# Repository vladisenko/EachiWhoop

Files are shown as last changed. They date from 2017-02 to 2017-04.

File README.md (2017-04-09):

# EachiWhoop v2

Changes compared to the v1:
- Upgrade CPU to STM32F303CCT6
- Add support AFHDS A2 protocol with telemetry (tested with FlySky FS-i6 transmitter)
- Add pads for the UART
- Board can operate with 2S battery (not tested yet)

# EachiWhoop

Micro size flight controller board for Eachine E010 frame.

Specifications:
- Processor: STM32F103CB
- Gyro: MPU6500
- Receiver: Flysky AFHDS
- Weight: 1.44 grams
- Voltage: 1S Lipo battery input
- Firmware: patched Betaflight

PCB with "2oz 0.8mm" option from [OSH Park](https://oshpark.com/shared_projects/v77xm6IP).

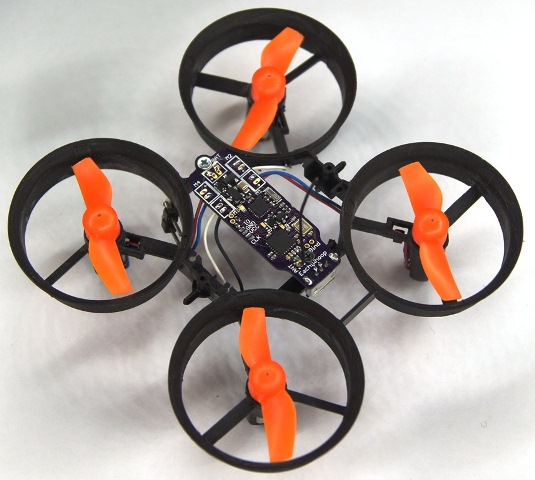
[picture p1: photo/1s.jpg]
pcb on E010 frame


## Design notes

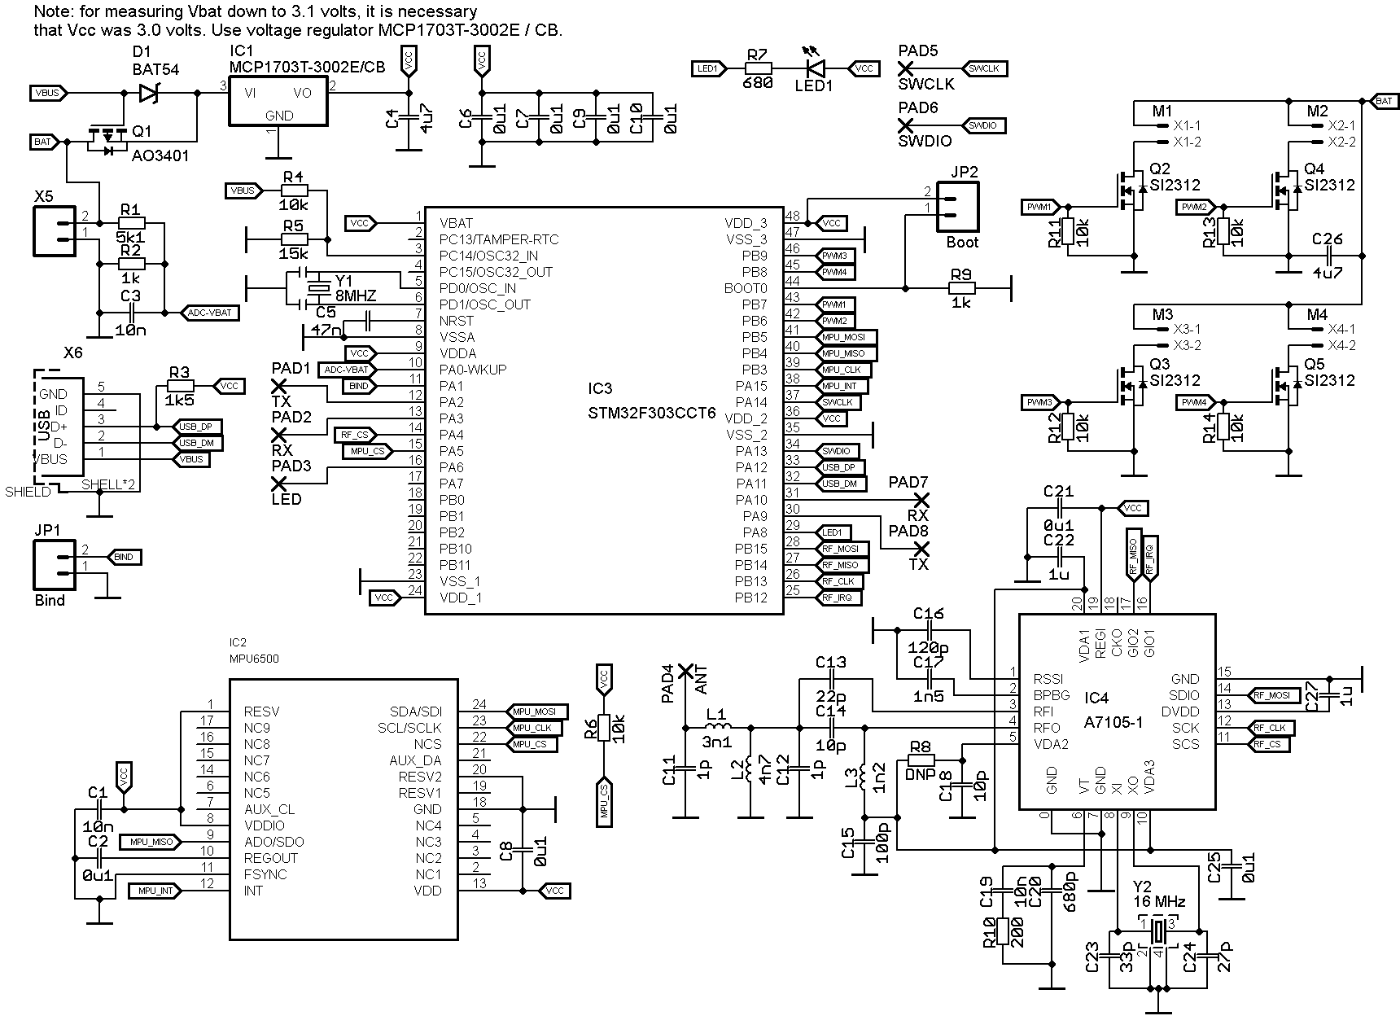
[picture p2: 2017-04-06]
hw/v.2/eachi-v2-schematic.png

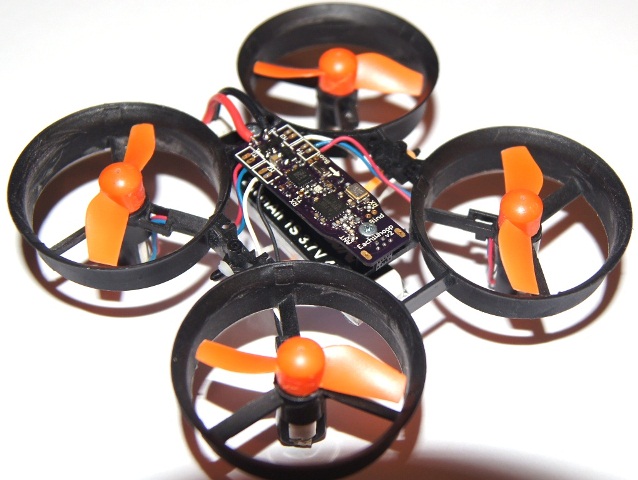
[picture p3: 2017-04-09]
photo/4s.JPG

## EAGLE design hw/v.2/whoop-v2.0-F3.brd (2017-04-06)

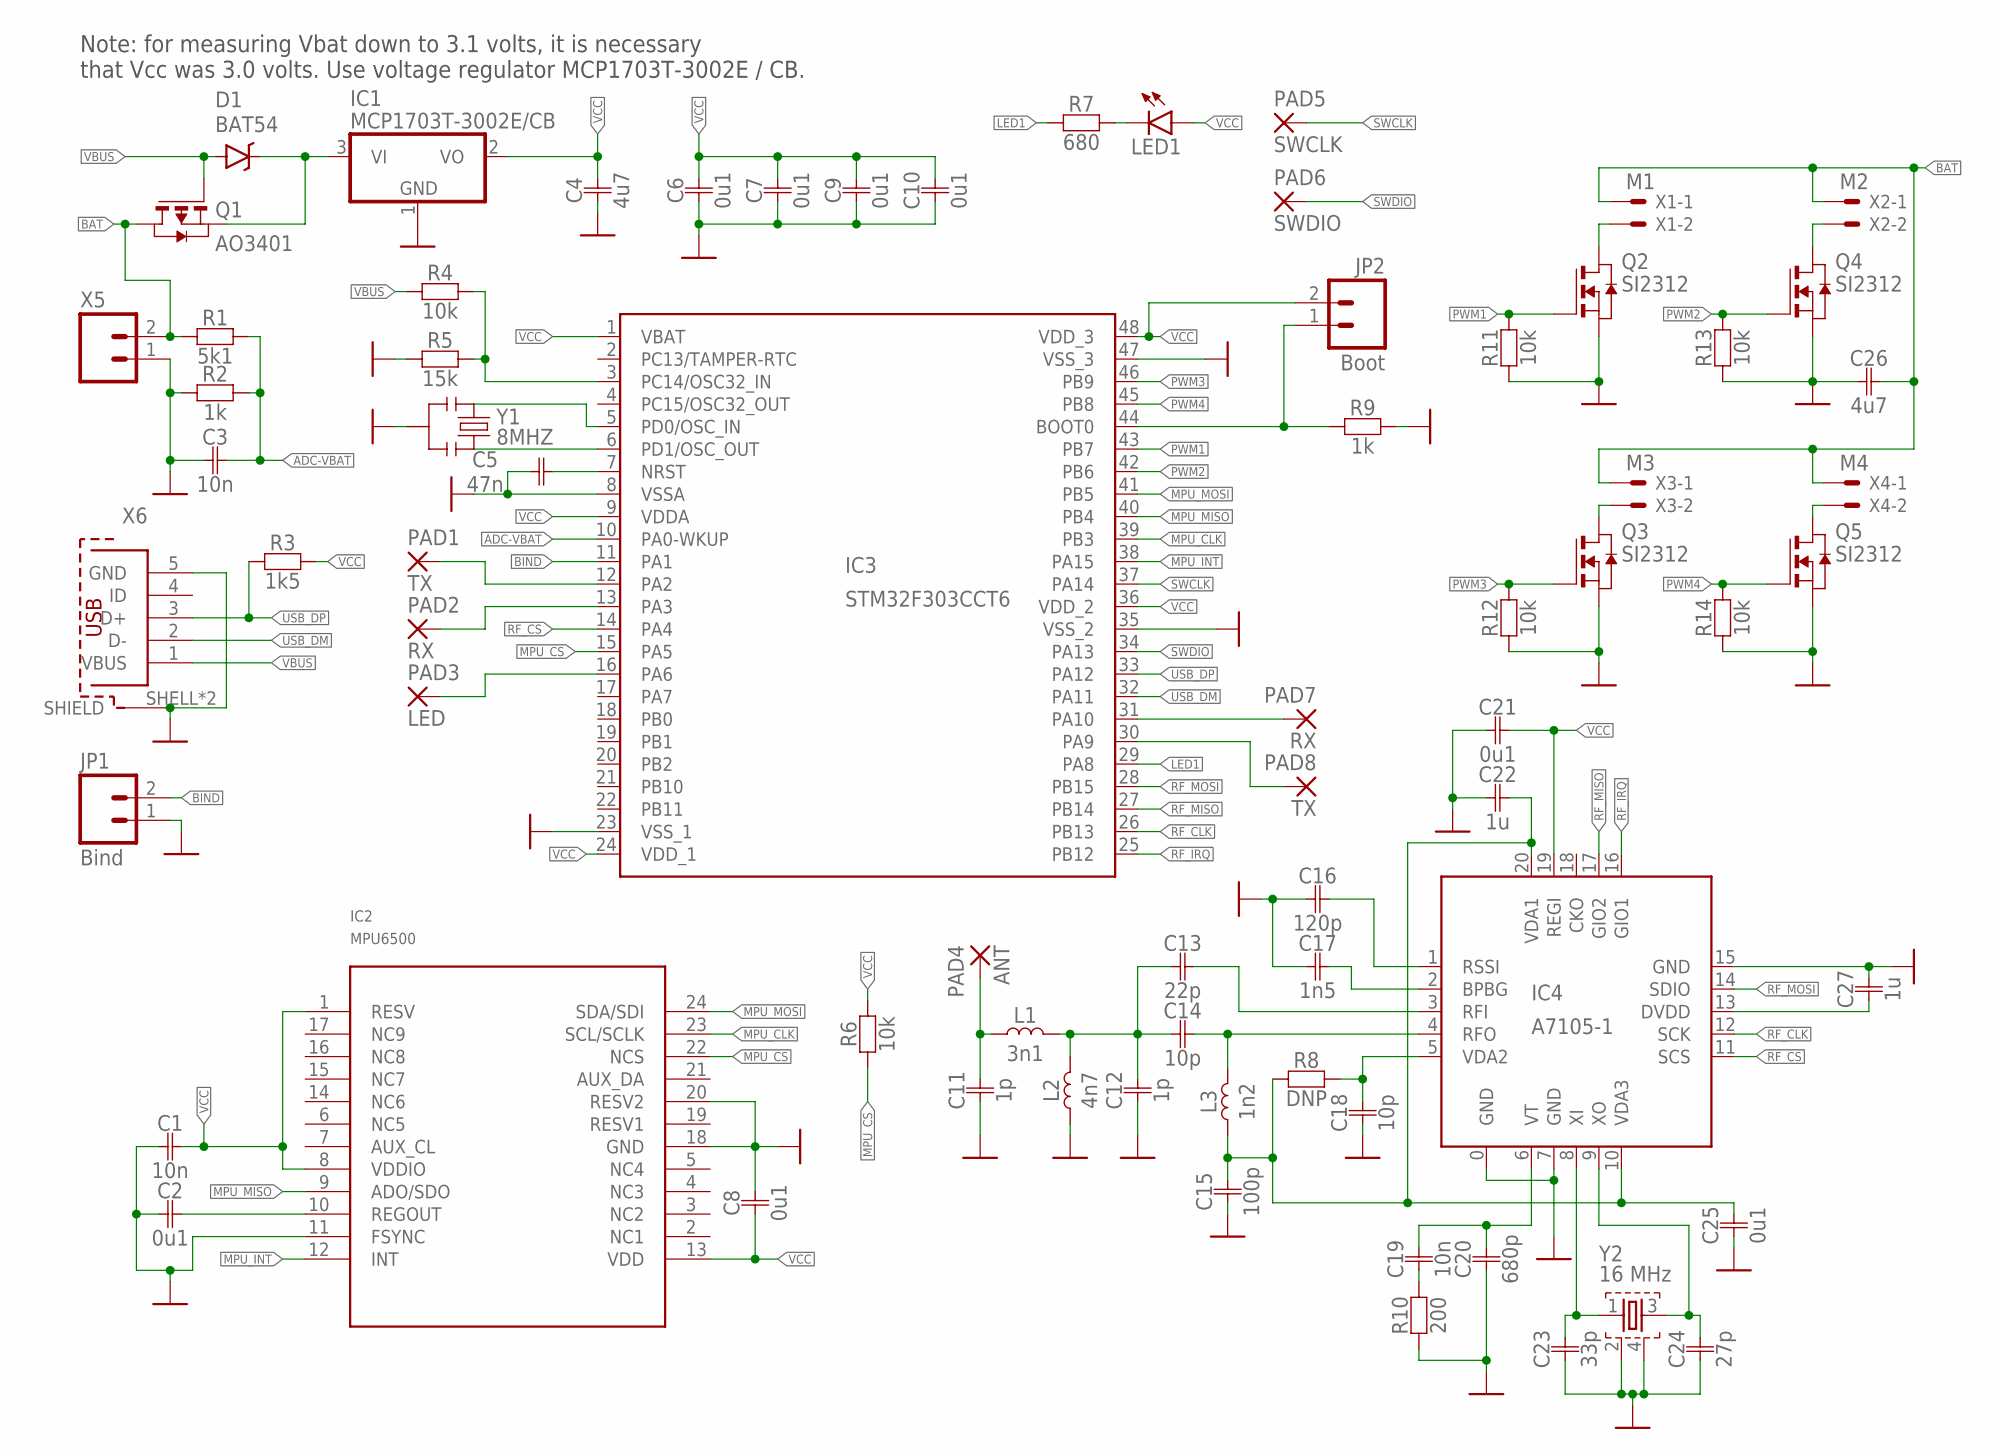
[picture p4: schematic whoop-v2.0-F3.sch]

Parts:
C1, C3, C19: 10n; 0402
C2, C6, C7, C8, C9, C10, C21, C25: 0u1; 0402
C4, C26: 4u7; 0805
C5: 47n; 0402
C11, C12: 1p; 0402
C13: 22p; 0402
C14, C18: 10p; 0402
C15: 100p; 0402
C16: 120p; 0402
C17: 1n5; 0402
C20: 680p; 0402
C22, C27: 1u; 0402
C23: 33p; 0402
C24: 27p; 0402
D1: BAT54; SOD-323
IC1: MCP1703T-3002E/CB; SOT23
IC2: MPU6500; LEAD-QFN24
IC3: STM32F303CCT6; LQFP48
IC4: A7105-1; QFN20-1
JP1: Bind; 1X02_1.27MM
JP2: Boot; 1X02_1.27MM
L1: 3n1; 0402
L2: 4n7; 0402
L3: 1n2; 0402
LED1: LED-RED0603; LED-0603
PAD1: TX; SMD_R0,635
PAD2, PAD7: RX; 1/0,6
PAD3: LED; 1/0,6
PAD4: ANT; 1/0,6
PAD5: SWCLK; SMD_R0,635
PAD6: SWDIO; SMD_R0,635
PAD8: TX; 1/0,6
Q1: AO3401; SOT-23
Q2, Q3, Q4, Q5: SI2312; SOT-23
R1: 5k1; 0402
R2, R9: 1k; 0402
R3: 1k5; 0402
R4, R6, R11, R12, R13, R14: 10k; 0402
R5: 15k; 0402
R7: 680; 0402
R8: DNP; 0402
R10: 200; 0402
X1: M1; 53047-02
X2: M2; 53047-02
X3: M3; 53047-02
X4: M4; 53047-02
X5: M022MM; 1X02_2MM
X6: 614105150721
Y1: 8MHZ; RESONATOR-SMD
Y2: 16 MHz; FA-20H

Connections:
ADC-VBAT: C3.P$2, IC3.10 (PA0-WKUP), R1.P$1, R2.P$1
BAT: C26.P$2, Q1.1 (D), R1.P$2, X1.1, X2.1, X3.1, X4.1, X5.2
BIND: IC3.11 (PA1), JP1.2
GND: C1.P$1, C2.P$1, C3.P$1, C4.P$1, C5.P$1, C6.P$1, C7.P$1, C8.P$2, C9.P$1, C10.P$1, C11.P$1, C12.P$1, C15.P$1, C16.P$1, C17.P$1, C18.P$1, C20.P$1, C21.P$1, C22.P$1, C23.P$1, C24.P$1, C25.P$1, C26.P$1, C27.P$2, IC1.1 (GND), IC2.11 (FSYNC), IC2.18 (GND), IC2.20 (RESV2), IC3.8 (VSSA), IC3.23 (VSS_1), IC3.35 (VSS_2), IC3.47 (VSS_3), IC4.0 (GND), IC4.7 (GND), IC4.15 (GND), JP1.1, L2.P$1, Q2.2 (S), Q3.2 (S), Q4.2 (S), Q5.2 (S), R2.P$2, R5.P$2, R9.P$2, R10.P$1, R11.P$1, R12.P$1, R13.P$1, R14.P$1, X5.1, X6.5 (GND), X6.SHELL (SHIELD), X6.SHELL1 (SHIELD), Y1.2, Y2.2, Y2.4
LED1: IC3.29 (PA8), R7.P$1
M1+: Q2.1 (D), X1.2
M2+: Q4.1 (D), X2.2
M3+: Q3.1 (D), X3.2
M4+: Q5.1 (D), X4.2
MPU_CLK: IC2.23 (SCL/SCLK), IC3.39 (PB3)
MPU_CS: IC2.22 (NCS), IC3.15 (PA5), R6.P$1
MPU_INT: IC2.12 (INT), IC3.38 (PA15)
MPU_MISO: IC2.9 (ADO/SDO), IC3.40 (PB4)
MPU_MOSI: IC2.24 (SDA/SDI), IC3.41 (PB5)
unnamed: C13.P$2, IC4.3 (RFI)
unnamed: C12.P$2, C13.P$1, C14.P$1, L1.P$2, L2.P$2
unnamed: C2.P$2, IC2.10 (REGOUT)
unnamed: C14.P$2, IC4.4 (RFO), L3.P$1
unnamed: C23.P$2, IC4.8 (XI), Y2.1
unnamed: C24.P$2, IC4.9 (XO), Y2.3
unnamed: C17.P$2, IC4.2 (BPBG)
unnamed: C16.P$2, IC4.1 (RSSI)
unnamed: C19.P$2, C20.P$2, IC4.6 (VT)
unnamed: C27.P$1, IC4.13 (DVDD)
unnamed: C19.P$1, R10.P$2
unnamed: C15.P$2, C22.P$2, C25.P$2, IC4.10 (VDA3), IC4.20 (VDA1), L3.P$2, R8.P$1
unnamed: IC3.6 (PD1/OSC_OUT), Y1.3
unnamed: C18.P$2, IC4.5 (VDA2), R8.P$2
unnamed: LED1.C, R7.P$2
unnamed: IC3.12 (PA2), PAD1.1
unnamed: IC3.3 (PC14/OSC32_IN), R4.P$2, R5.P$1
unnamed: IC3.13 (PA3), PAD2.1
unnamed: IC3.44 (BOOT0), JP2.1, R9.P$1
unnamed: C11.P$2, L1.P$1, PAD4.1
unnamed: IC3.31 (PA10), PAD7.1
unnamed: IC3.16 (PA6), PAD3.1
unnamed: IC3.30 (PA9), PAD8.1
unnamed: IC3.5 (PD0/OSC_IN), Y1.1
unnamed: D1.C, IC1.3 (VI), Q1.2 (S)
unnamed: C5.P$2, IC3.7 (NRST)
PWM1: IC3.43 (PB7), Q2.3 (G), R11.P$2
PWM2: IC3.42 (PB6), Q4.3 (G), R13.P$2
PWM3: IC3.46 (PB9), Q3.3 (G), R12.P$2
PWM4: IC3.45 (PB8), Q5.3 (G), R14.P$2
RF_CLK: IC3.26 (PB13), IC4.12 (SCK)
RF_CS: IC3.14 (PA4), IC4.11 (SCS)
RF_IRQ: IC3.25 (PB12), IC4.16 (GIO1)
RF_MISO: IC3.27 (PB14), IC4.17 (GIO2)
RF_MOSI: IC3.28 (PB15), IC4.14 (SDIO)
SWCLK: IC3.37 (PA14), PAD5.1
SWDIO: IC3.34 (PA13), PAD6.1
USB_DM: IC3.32 (PA11), X6.2 (D-)
USB_DP: IC3.33 (PA12), R3.P$2, X6.3 (D+)
VBUS: D1.A, Q1.3 (G), R4.P$1, X6.1 (VBUS)
VCC: C1.P$2, C4.P$2, C6.P$2, C7.P$2, C8.P$1, C9.P$2, C10.P$2, C21.P$2, IC1.2 (VO), IC2.1 (RESV), IC2.8 (VDDIO), IC2.13 (VDD), IC3.1 (VBAT), IC3.9 (VDDA), IC3.24 (VDD_1), IC3.36 (VDD_2), IC3.48 (VDD_3), IC4.19 (REGI), JP2.2, LED1.A, R3.P$1, R6.P$2

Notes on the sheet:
Note: for measuring Vbat down to 3.1 volts, it is necessary that Vcc was 3.0 volts. Use voltage regulator MCP1703T-3002E / CB.

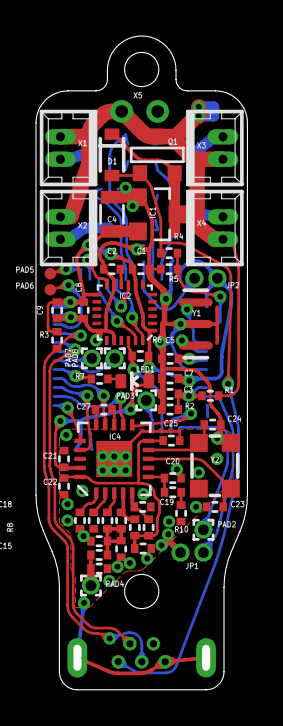
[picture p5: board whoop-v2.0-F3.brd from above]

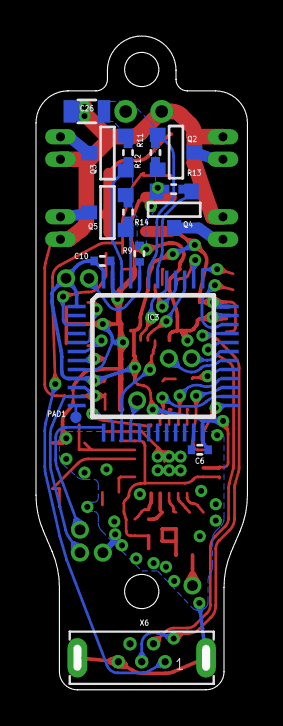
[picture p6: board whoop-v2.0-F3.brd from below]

Board: 2 copper layers, 11.7 x 36.3 mm, 73 parts (15 on the bottom side), 55 nets.

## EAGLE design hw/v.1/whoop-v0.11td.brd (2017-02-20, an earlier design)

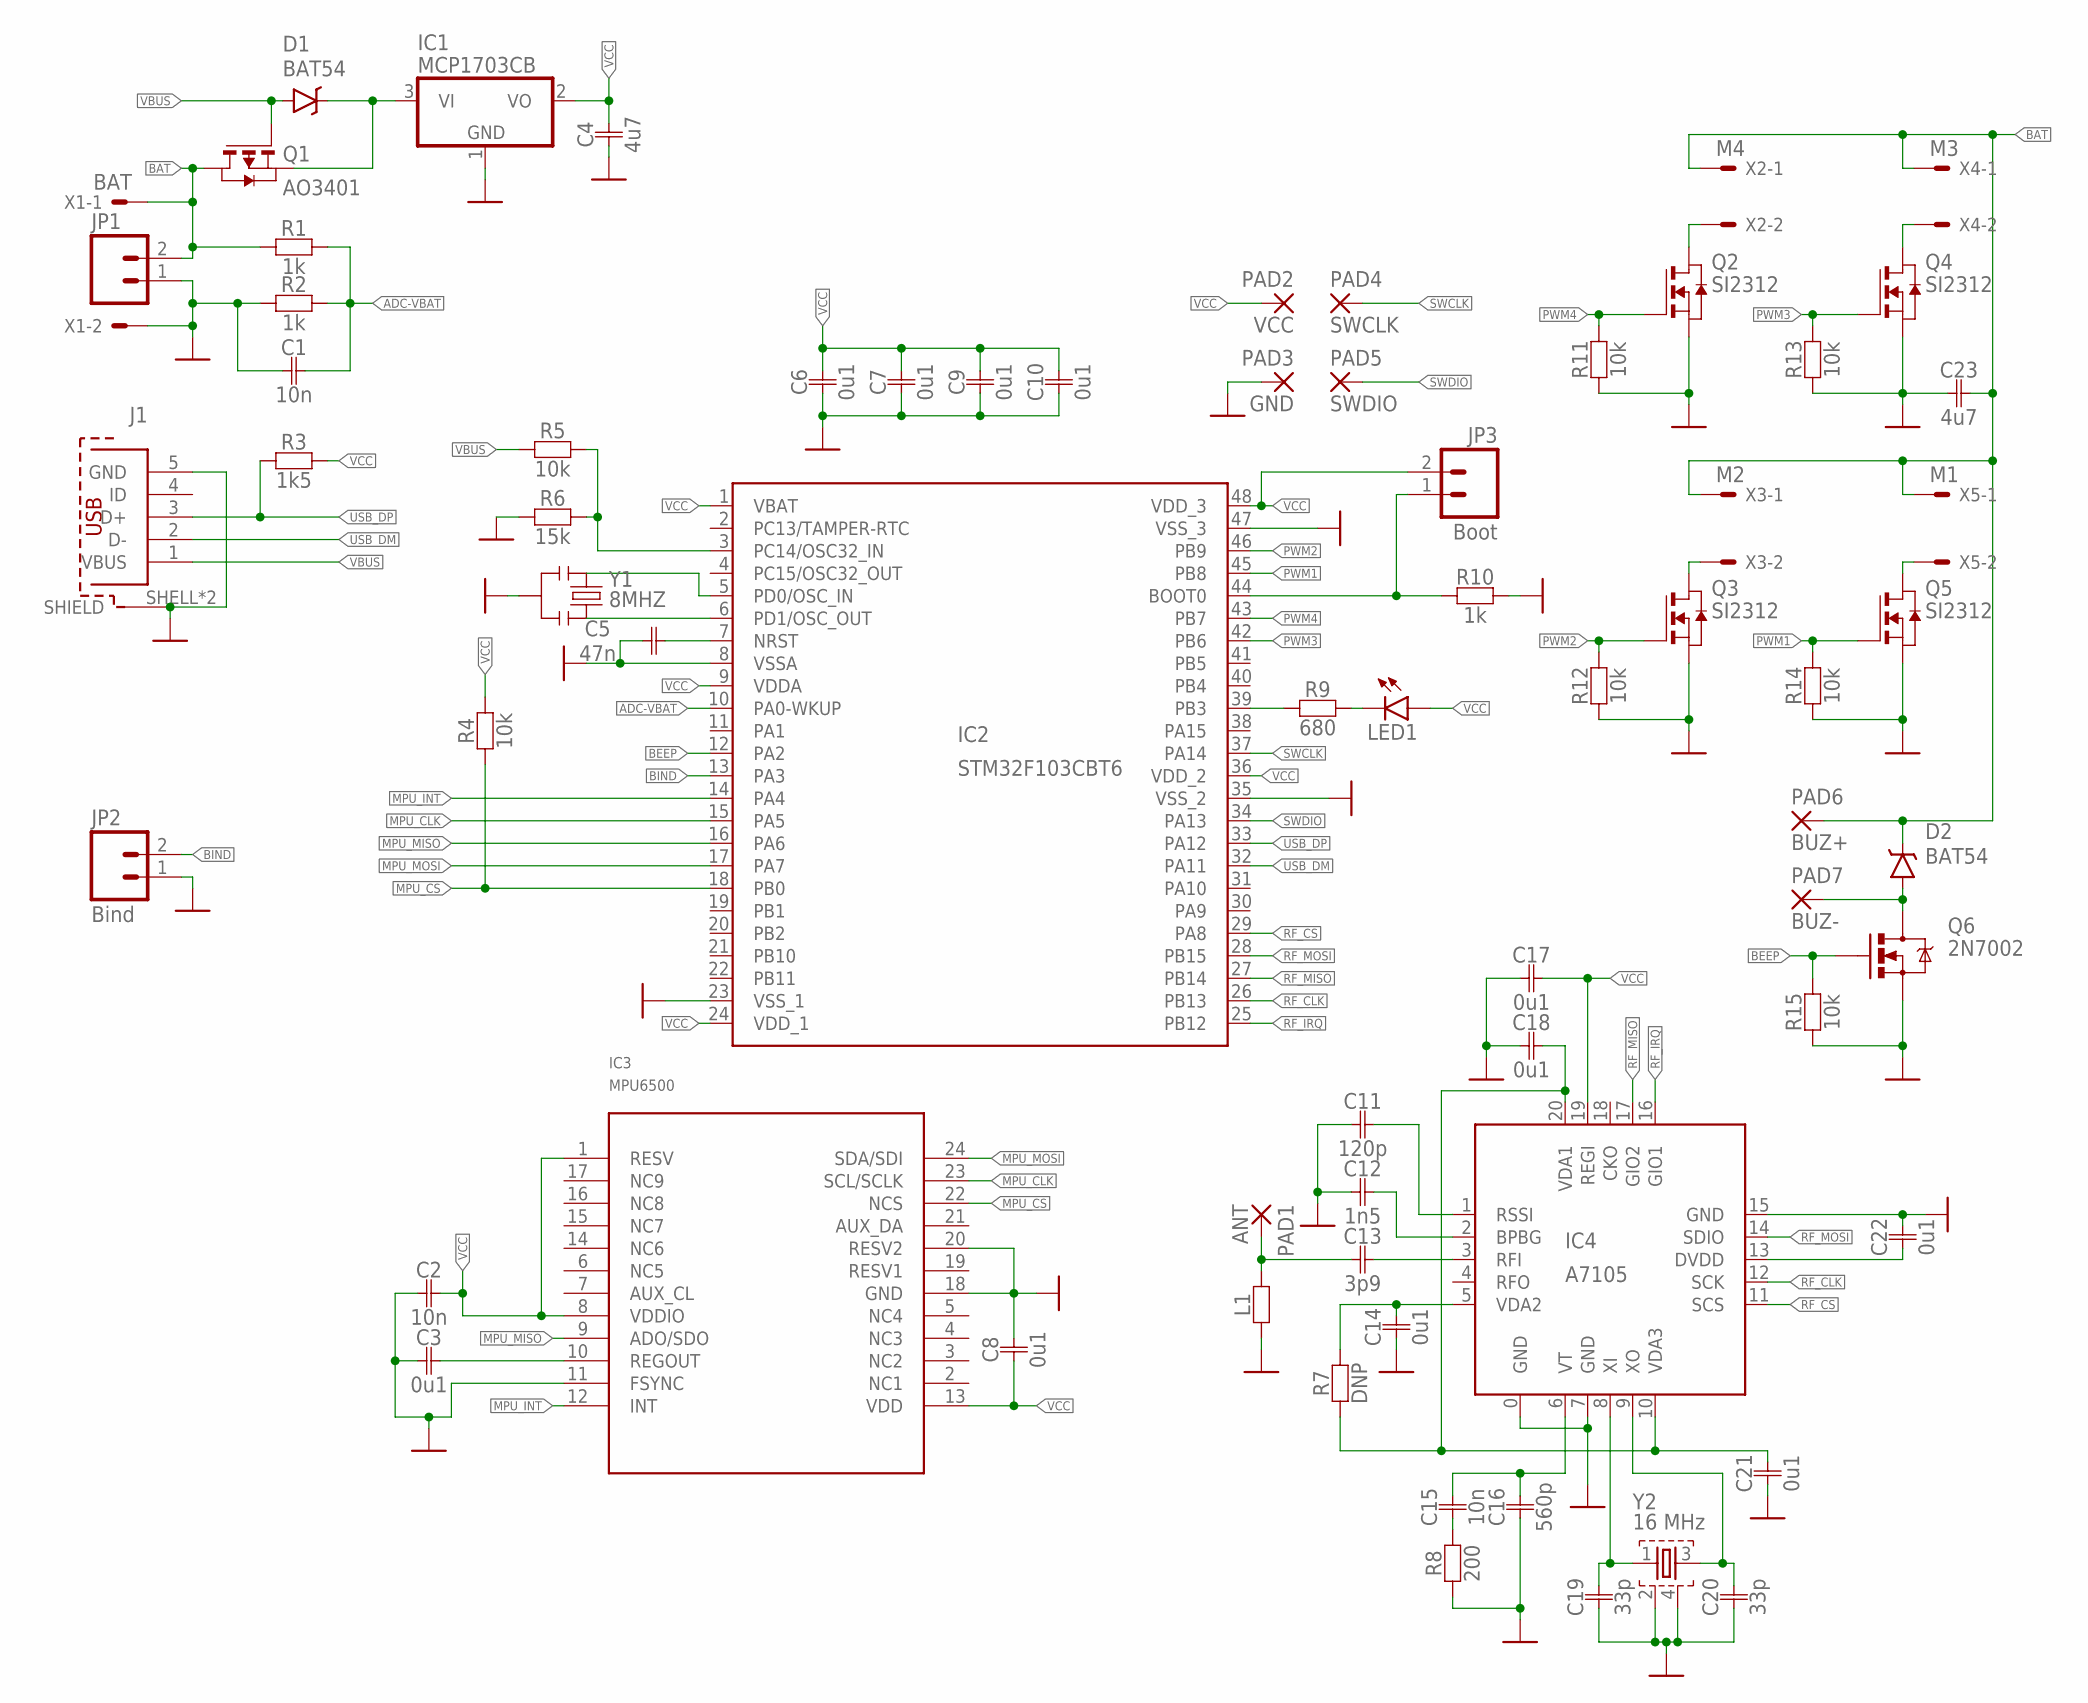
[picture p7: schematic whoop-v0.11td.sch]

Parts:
C1, C2, C15: 10n; 0402
C3, C6, C7, C8, C9, C10, C14, C17, C18, C21, C22: 0u1; 0402
C4, C23: 4u7; 0805
C5: 47n; 0402
C11: 120p; 0402
C12: 1n5; 0402
C13: 3p9; 0402
C16: 560p; 0402
C19, C20: 33p; 0402
D1, D2: BAT54; SOD-323
IC1: MCP1703CB; SOT23
IC2: STM32F103CBT6; LQFP48
IC3: MPU6500; LEAD-QFN24
IC4: A7105; QFN20
J1: 614105150721
JP1: M022MM; 1X02_2MM
JP2: Bind; 1X02_1.27MM
JP3: Boot; 1X02_1.27MM
L1: R0402; 0402
LED1: LED-RED0603; LED-0603
PAD1: ANT; 1,6/0,8
PAD2: VCC; SMD1,27-2,54
PAD3: GND; SMD1,27-2,54
PAD4: SWCLK; SMD1,27-2,54
PAD5: SWDIO; SMD1,27-2,54
PAD6: BUZ+; SMD1,27-2,54
PAD7: BUZ-; SMD1,27-2,54
Q1: AO3401; SOT-23
Q2, Q3, Q4, Q5: SI2312; SOT-23
Q6: 2N7002; SOT323
R1, R2, R10: 1k; 0402
R3: 1k5; 0402
R4, R5, R11, R12, R13, R14, R15: 10k; 0402
R6: 15k; 0402
R7: DNP; 0402
R8: 200; 0402
R9: 680; 0402
X1: BAT; 53047-02
X2: M4; 53047-02
X3: M2; 53047-02
X4: M3; 53047-02
X5: M1; 53047-02
Y1: 8MHZ; RESONATOR-SMD
Y2: 16 MHz; FA-20H

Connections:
ADC-VBAT: C1.P$2, IC2.10 (PA0-WKUP), R1.P$1, R2.P$1
BAT: C23.P$2, D2.C, JP1.2, PAD6.1, Q1.1 (D), R1.P$2, X1.1, X2.1, X3.1, X4.1, X5.1
BEEP: IC2.12 (PA2), Q6.1 (G), R15.P$2
BIND: IC2.13 (PA3), JP2.2
GND: C1.P$1, C2.P$1, C3.P$1, C4.P$1, C5.P$1, C6.P$1, C7.P$1, C8.P$2, C9.P$1, C10.P$1, C11.P$1, C12.P$1, C14.P$1, C16.P$1, C17.P$1, C18.P$1, C19.P$1, C20.P$1, C21.P$1, C22.P$2, C23.P$1, IC1.1 (GND), IC2.8 (VSSA), IC2.23 (VSS_1), IC2.35 (VSS_2), IC2.47 (VSS_3), IC3.11 (FSYNC), IC3.18 (GND), IC3.20 (RESV2), IC4.0 (GND), IC4.7 (GND), IC4.15 (GND), J1.5 (GND), J1.SHELL (SHIELD), J1.SHELL1 (SHIELD), JP1.1, JP2.1, L1.P$1, PAD3.1, Q2.2 (S), Q3.2 (S), Q4.2 (S), Q5.2 (S), Q6.2 (S), R2.P$2, R6.P$2, R8.P$1, R10.P$2, R11.P$1, R12.P$1, R13.P$1, R14.P$1, R15.P$1, X1.2, Y1.2, Y2.2, Y2.4
M1+: Q2.1 (D), X2.2
M2+: Q4.1 (D), X4.2
M3+: Q3.1 (D), X3.2
M4+: Q5.1 (D), X5.2
MPU_CLK: IC2.15 (PA5), IC3.23 (SCL/SCLK)
MPU_CS: IC2.18 (PB0), IC3.22 (NCS), R4.P$1
MPU_INT: IC2.14 (PA4), IC3.12 (INT)
MPU_MISO: IC2.16 (PA6), IC3.9 (ADO/SDO)
MPU_MOSI: IC2.17 (PA7), IC3.24 (SDA/SDI)
unnamed: C13.P$2, IC4.3 (RFI)
unnamed: D2.A, PAD7.1, Q6.3 (D)
unnamed: C3.P$2, IC3.10 (REGOUT)
unnamed: C13.P$1, L1.P$2, PAD1.1
unnamed: C19.P$2, IC4.8 (XI), Y2.1
unnamed: C20.P$2, IC4.9 (XO), Y2.3
unnamed: C12.P$2, IC4.2 (BPBG)
unnamed: C11.P$2, IC4.1 (RSSI)
unnamed: C15.P$2, C16.P$2, IC4.6 (VT)
unnamed: C22.P$1, IC4.13 (DVDD)
unnamed: C15.P$1, R8.P$2
unnamed: C18.P$2, C21.P$2, IC4.10 (VDA3), IC4.20 (VDA1), R7.P$1
unnamed: IC2.6 (PD1/OSC_OUT), Y1.3
unnamed: C14.P$2, IC4.5 (VDA2), R7.P$2
unnamed: LED1.C, R9.P$2
unnamed: IC2.39 (PB3), R9.P$1
unnamed: IC2.3 (PC14/OSC32_IN), R5.P$2, R6.P$1
unnamed: IC2.44 (BOOT0), JP3.1, R10.P$1
unnamed: IC2.5 (PD0/OSC_IN), Y1.1
unnamed: D1.C, IC1.3 (VI), Q1.2 (S)
unnamed: C5.P$2, IC2.7 (NRST)
PWM1: IC2.45 (PB8), Q5.3 (G), R14.P$2
PWM2: IC2.46 (PB9), Q3.3 (G), R12.P$2
PWM3: IC2.42 (PB6), Q4.3 (G), R13.P$2
PWM4: IC2.43 (PB7), Q2.3 (G), R11.P$2
RF_CLK: IC2.26 (PB13), IC4.12 (SCK)
RF_CS: IC2.29 (PA8), IC4.11 (SCS)
RF_IRQ: IC2.25 (PB12), IC4.16 (GIO1)
RF_MISO: IC2.27 (PB14), IC4.17 (GIO2)
RF_MOSI: IC2.28 (PB15), IC4.14 (SDIO)
SWCLK: IC2.37 (PA14), PAD4.1
SWDIO: IC2.34 (PA13), PAD5.1
USB_DM: IC2.32 (PA11), J1.2 (D-)
USB_DP: IC2.33 (PA12), J1.3 (D+), R3.P$2
VBUS: D1.A, J1.1 (VBUS), Q1.3 (G), R5.P$1
VCC: C2.P$2, C4.P$2, C6.P$2, C7.P$2, C8.P$1, C9.P$2, C10.P$2, C17.P$2, IC1.2 (VO), IC2.1 (VBAT), IC2.9 (VDDA), IC2.24 (VDD_1), IC2.36 (VDD_2), IC2.48 (VDD_3), IC3.1 (RESV), IC3.8 (VDDIO), IC3.13 (VDD), IC4.19 (REGI), JP3.2, LED1.A, PAD2.1, R3.P$1, R4.P$2

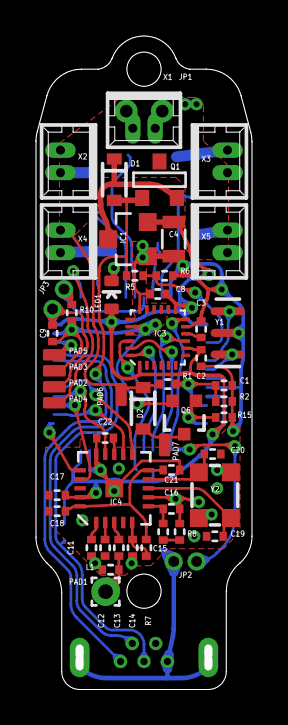
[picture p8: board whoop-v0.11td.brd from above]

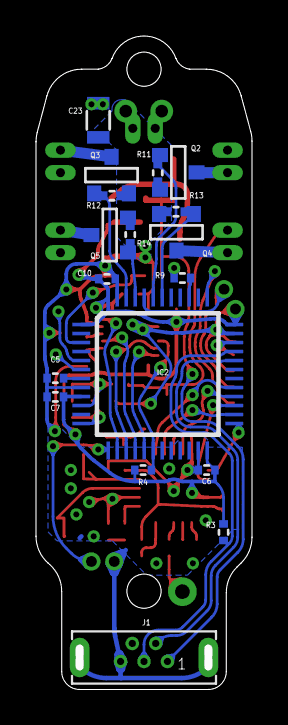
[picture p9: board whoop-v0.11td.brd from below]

Board: 2 copper layers, 12.0 x 36.3 mm, 70 parts (18 on the bottom side), 50 nets.

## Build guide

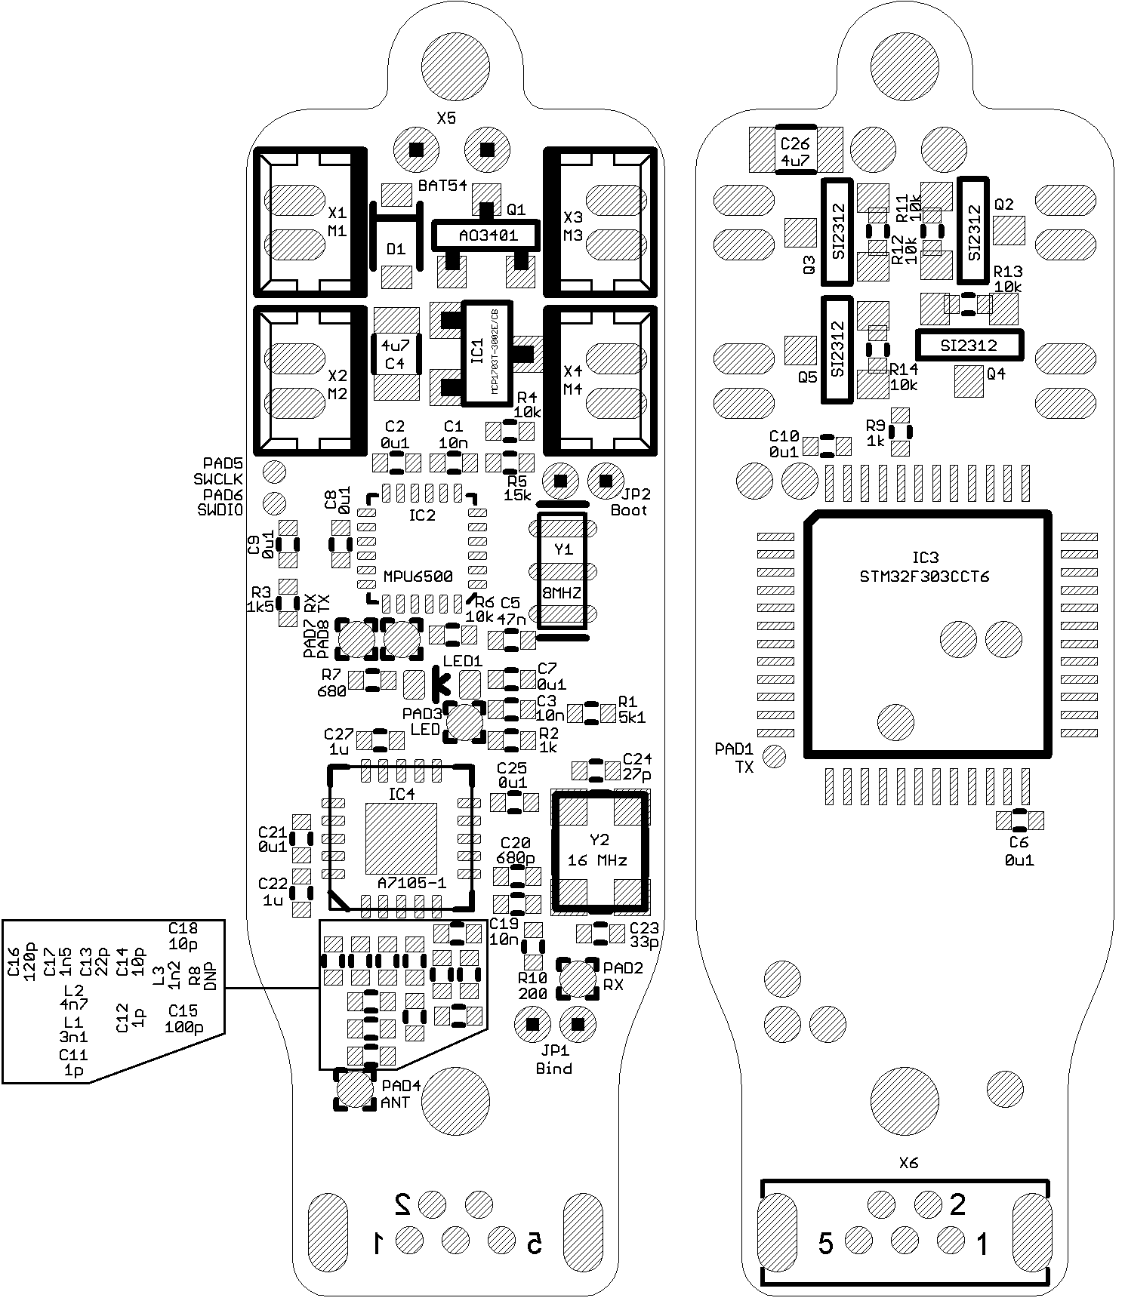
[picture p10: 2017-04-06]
hw/v.2/eachi-v2-assembly.png

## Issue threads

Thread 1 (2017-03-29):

Isolating AFHDS 2A code

trogalko, 2017-03-29:
Hi, your code is the first AFHDS 2A receiver implementation I found.
This is not exactly an issue, but more like a request :
Could You create a wiki about compiling and/or patching your code to the betaflight source?
I'm interesting in isolating the receiver code to make a diy AFHDS 2A receiver.
Thank You,

vladisenko, 2017-03-29:
Hi. In two weeks I will receive the PCB v.2 and test it. After that I will publish source code and write manual.
In plans to make a separate receiver on the STM32F030F4.

trogalko, 2017-04-07:
That's great news, thank You

jamedavid2017, 2017-04-23:
Hi . Can you off telemetry on V2 ?  I want to build version ahfds 2a  outdoor .

HackIT, 2017-04-23:
You should learn to code my friend... it's not hard... :)

hustler4life, 2018-01-17:
How get EachiWhoop v2 Finished product

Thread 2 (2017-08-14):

short range  and add PA/LNA

jamedavid2017, 2017-08-14:
hi vladisenko

i tried  version v2 and it worked . However  , i get short range with telemetry , So i think should add a PA/LNA  chip to improve range .
RFX2402  or others .

thanks

vladisenko, 2017-08-14:
Hello! How many meters you are got? At this moment I ordered another version of PCB with RFX2401, but not tested yet.

jamedavid2017, 2017-08-14:
hi  vladisenko

i only can get <30m with I6 . I need range better  to fly where many obstacle , you can up  new firmwre here , or my email ?  i can test with RFX2401 , i had it .
And which is two pin TX/RX for rfx2401 ?
my mail jamedavid300688@gmail.com

vladisenko, 2017-08-14:
RXEN always connect to 3.3v in my PCB. Only one pin needs to control RFX2401. Code has not yet been written, but I try to write in a few days. What PCB do you use?

jamedavid2017, 2017-08-14:
hi
no problem with RXEN always 3v3 . i have modul mini a7105+ rfx2401  , a7105 single . So i can connect it easy.  I only make PCB F3 + MPU6500 .
i will follow firmware here . and will report result

phobos-, 2017-10-02:
Hi,
any update on this? I can see the code is ready for PA/LNA, but the hardware is still without the PA chip.
I'm facing the same issues, it's great for indoors, but outdoors behind trees is a no-go.

vladisenko, 2017-10-04:
The software is ready. But the hardware is not. I think for the Whoop there is no need for PA.
The software is tested on XL7105-D03 module connected to the original REVO via Flexi IO port.

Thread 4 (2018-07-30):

Onimbus F4  + a7105 full range

jonathan2018, 2018-07-30:
Hi developer

I saw your project with F3  , however  wonder FC availble Onimbus F4  , it support Port SPI  on main ,so connect  simple . Can you support code for it ?

I m sorry , i have not experience  about Code

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

vladisenko, 2018-08-02:
Hi.
You need two more pins to connect the transceiver - one for the IRQ and one for controlling the power amplifier. It is possible to connect only through these 4 pins but this requires changes in the driver a7105.

jonathan2018, 2018-08-03:
hi vladisenko
thanks for answer. I just find  your code use 5 pin for a7105 ( not yet PA ) sorry .
 i saw some project use A7105 PA  for modul tranmiter . maybe will lost many time to work with code to use 4 pin .

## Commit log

2017-02-19 first release
    [whoop-v0.11td.brd, whoop-v0.11td.sch]
2017-02-20 hw update
    [whoop-v0.11td.brd, whoop-v0.11td.sch]
2017-03-06 add v2 of hardware
    [whoop-v0.11td.brd, whoop-v0.11td.sch, whoop-v2.0-F3.brd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]
2017-04-06 edit some values
    [whoop-v2.0-F3.brd, whoop-v2.0-F3.sch]

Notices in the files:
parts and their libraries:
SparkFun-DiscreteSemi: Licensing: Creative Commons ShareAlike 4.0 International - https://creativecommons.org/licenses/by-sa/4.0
